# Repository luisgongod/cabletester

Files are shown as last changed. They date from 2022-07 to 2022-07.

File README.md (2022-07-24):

Eurorack Arduino 10/16 pin IDC Power Cable Tester
=================================================

Forked from [holmesrichards](https://github.com/holmesrichards/cabletester) Original idea and testing algorithm goes to [tomarus](https://github.com/tomarus/cabletester ). This version has a new PCB and Some modifications to the FW made into a Platformio project.

* It only tests (max) 8 wires because of how they're wired in eurorack.
* It can detect shorted cables or faulty/unconnected wires.
* Possible to run a _calibration_ sketch for more accurate readings.
* `GND-VCC-SCL-SDA` and `VCC-GND-SCL-SDA` Oled configuration allowed.
* JLCPCB Gerber ready zip

The original documentation and repo information is under _OGs_ folder. Gerbers, schematics and BOM are under _HW_ while the Platformio project is under _FW_.

# Calibration

Default values should work fine:
```
const int expect[] = {746, 544, 395, 286, 204, 130, 80, 35};
```
But is recommended to make a _calibration_ run to change to proper values. To do that:
- Define `DEBUG` mode by uncommenting line 7. 
- Plug a 16 pin Cable that is known to be work fine. 
- Flash the arduino and open Serialmonitor. the `expect` values will be printed, they should not differ too much from default values. 
- Change the `expect` values, comment the `DEBUG` define and re-flash

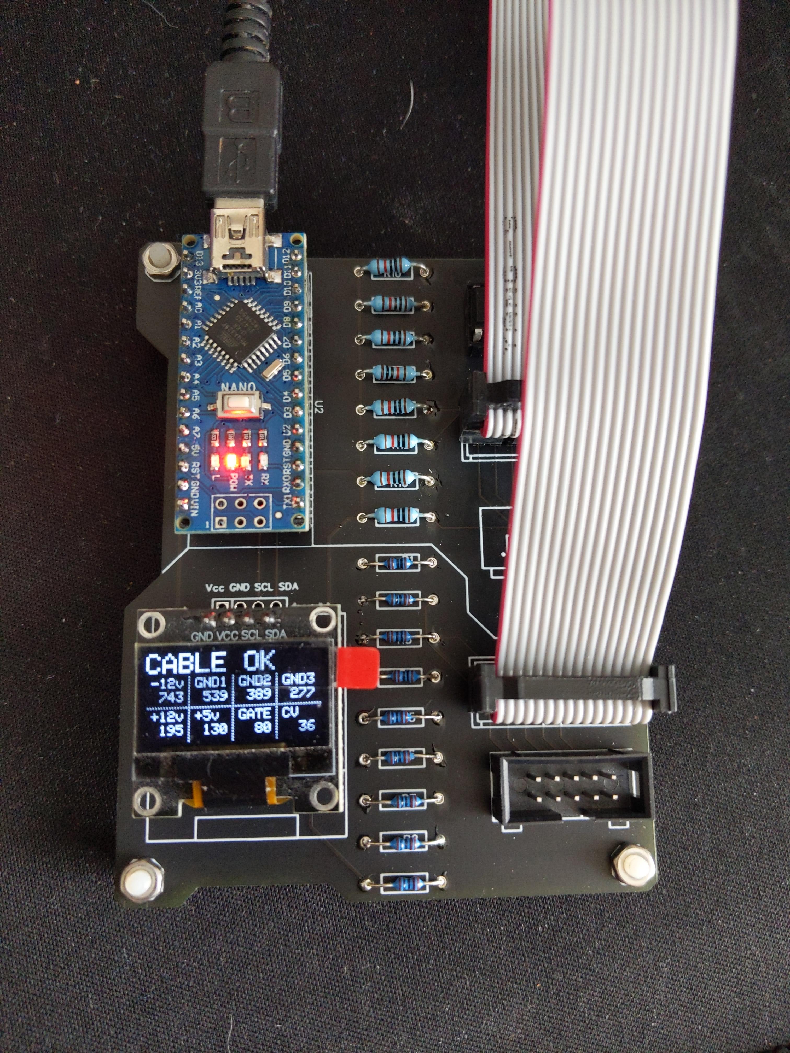
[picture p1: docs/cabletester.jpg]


# Schematics

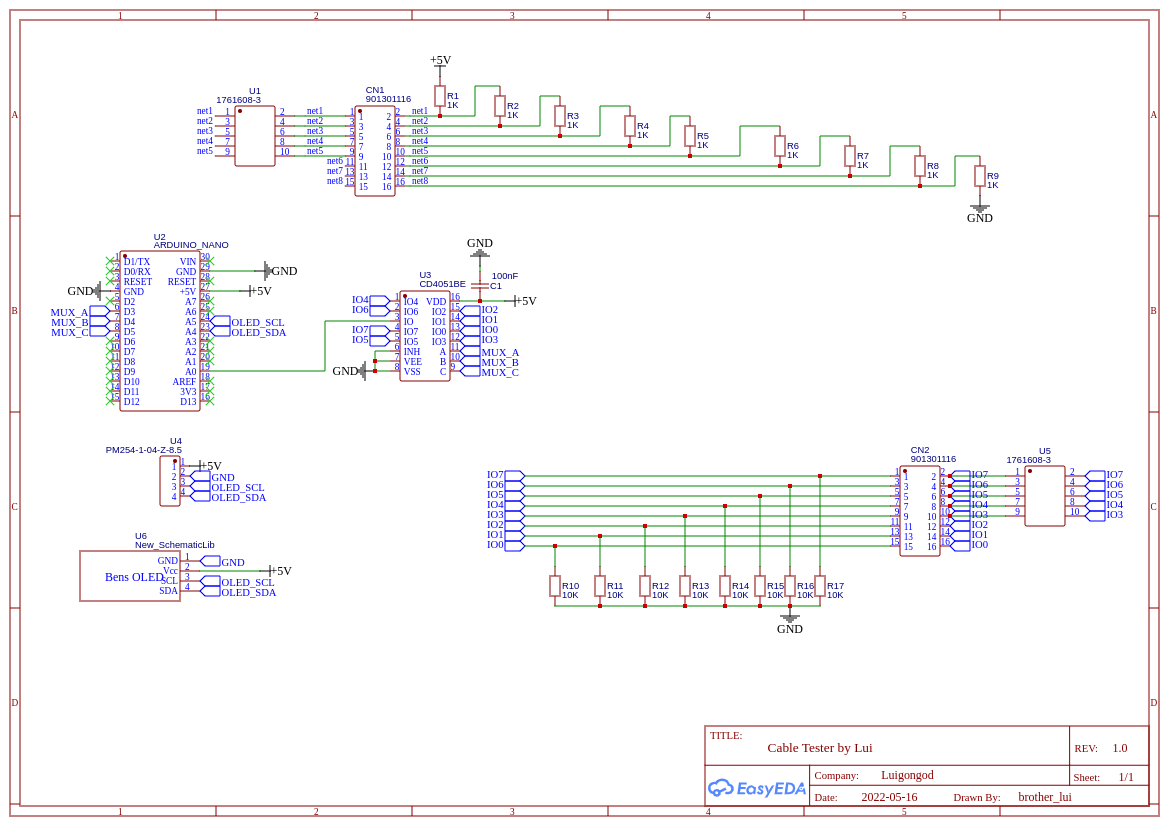
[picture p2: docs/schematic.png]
schematics


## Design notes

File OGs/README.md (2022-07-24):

Arduino 10/16 pin Eurorack IDC Power Cable Tester
=================================================

Forked from [https://github.com/tomarus/cabletester](https://github.com/tomarus/cabletester) with slight modifications to circuit and software (mainly order of connections), and with PCB layout added.

* It only tests (max) 8 wires because of how they're wired in eurorack.
* It can detect shorted cables or faulty/unconnected wires.

This project uses a 128x64 OLED I2C display module with four interface pins: GND, +12V, SCL, and SDA. It is a monochrome display although it is available in a version with a yellow and blue overlay as seen in the photos. Note that the OLED pinout sometimes is GND-VCC-SCL-SDA and sometimes VCC-GND-SCL-SDA. The initial run of boards assumed the latter pinout; the present design has footprints for both.

These modules are available from the "usual suspects" on Amazon, eBay, AliExpress, etc. I have one of [these](https://www.amazon.com/gp/product/B072Q2X2LL) (GND-VCC-SCL-SDA) and one of [these](https://www.amazon.com/gp/product/B07FK8GB8T) (VCC-GND-SCL-SDA). They do *not* seem to be available from any established vendors like Mouser, DigiKey, Tayda, Adafruit, or SparkFun. Please make sure you have a source for the display before proceeding with this project! 

Code uses these libraries:

* https://github.com/adafruit/Adafruit_SSD1306
* https://github.com/adafruit/Adafruit-GFX-Library

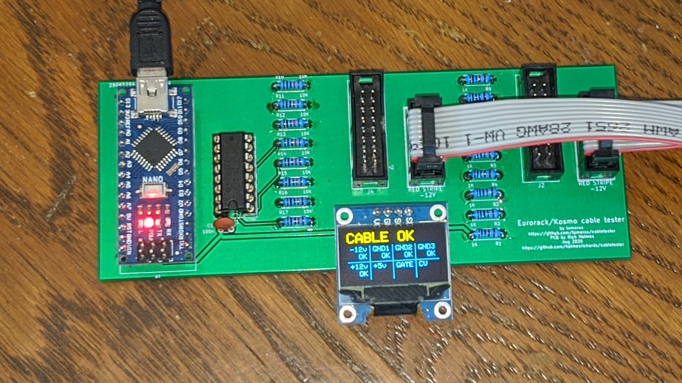
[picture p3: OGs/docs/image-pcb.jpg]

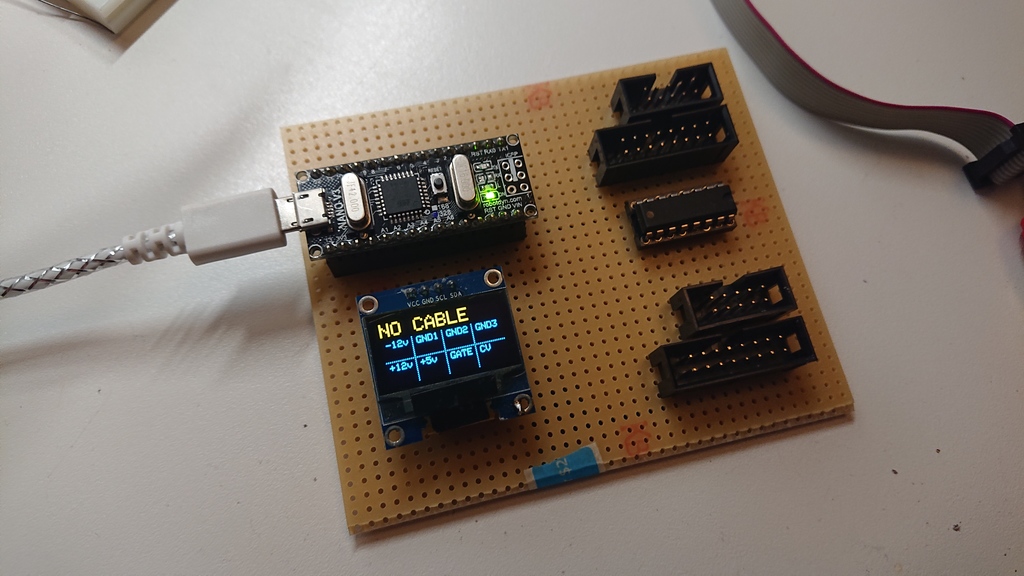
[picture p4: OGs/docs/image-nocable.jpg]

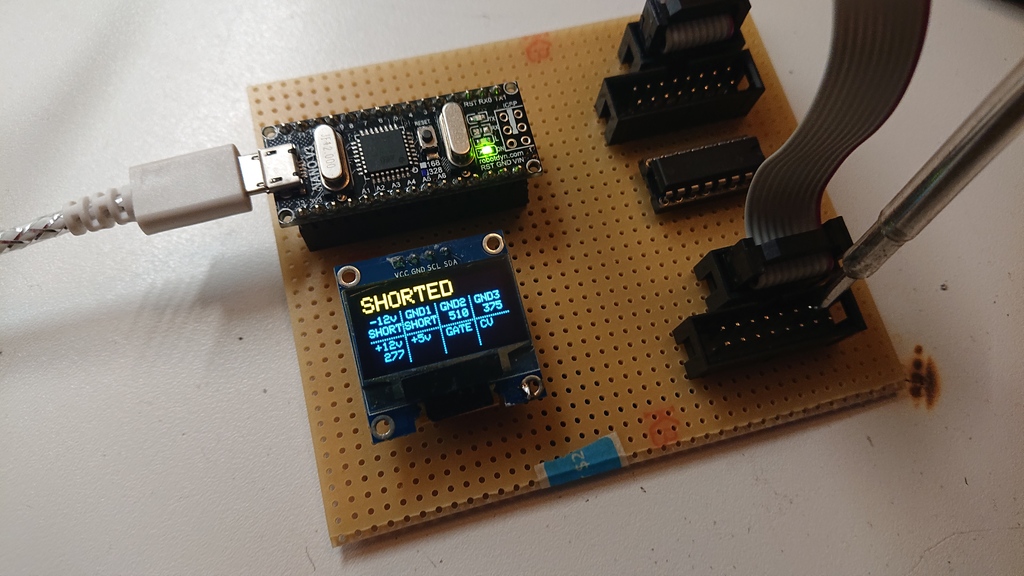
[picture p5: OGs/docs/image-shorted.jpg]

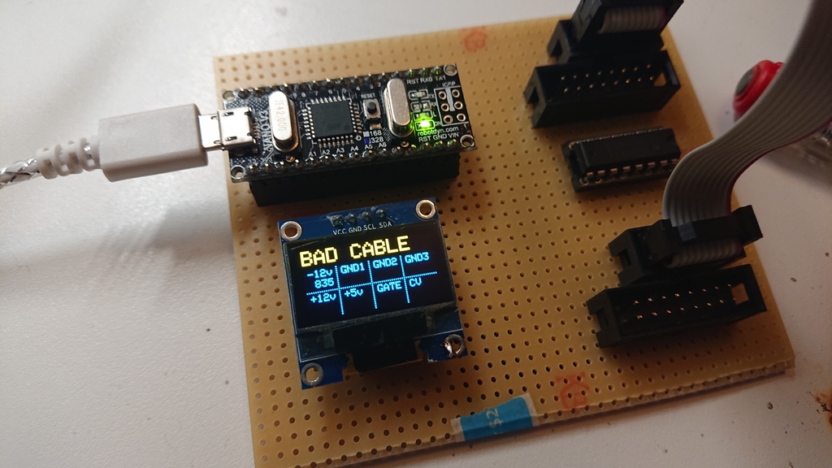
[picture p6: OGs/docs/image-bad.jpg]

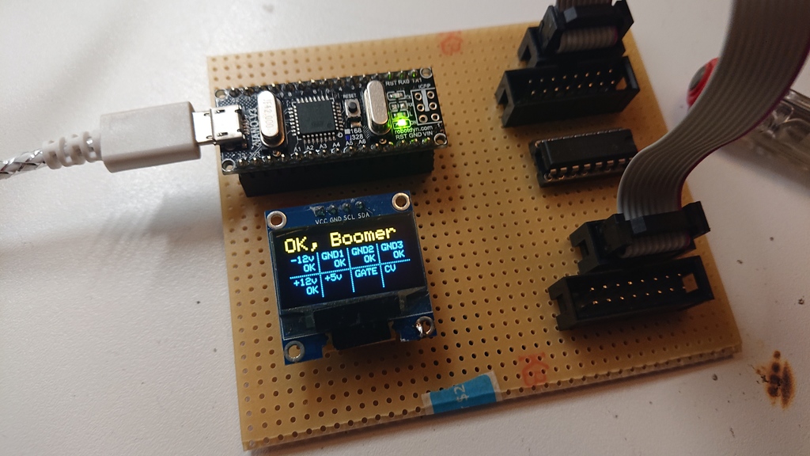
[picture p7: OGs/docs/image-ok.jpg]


# Schematics

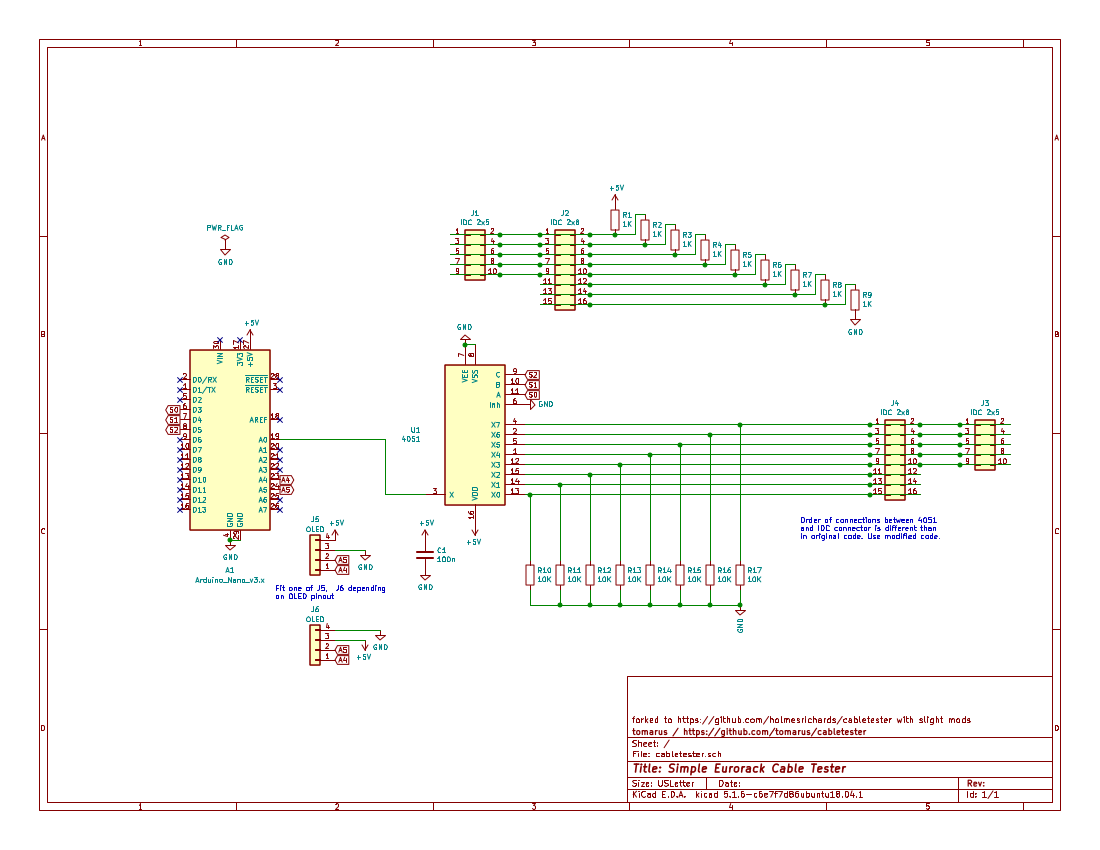
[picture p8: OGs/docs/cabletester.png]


# PCB

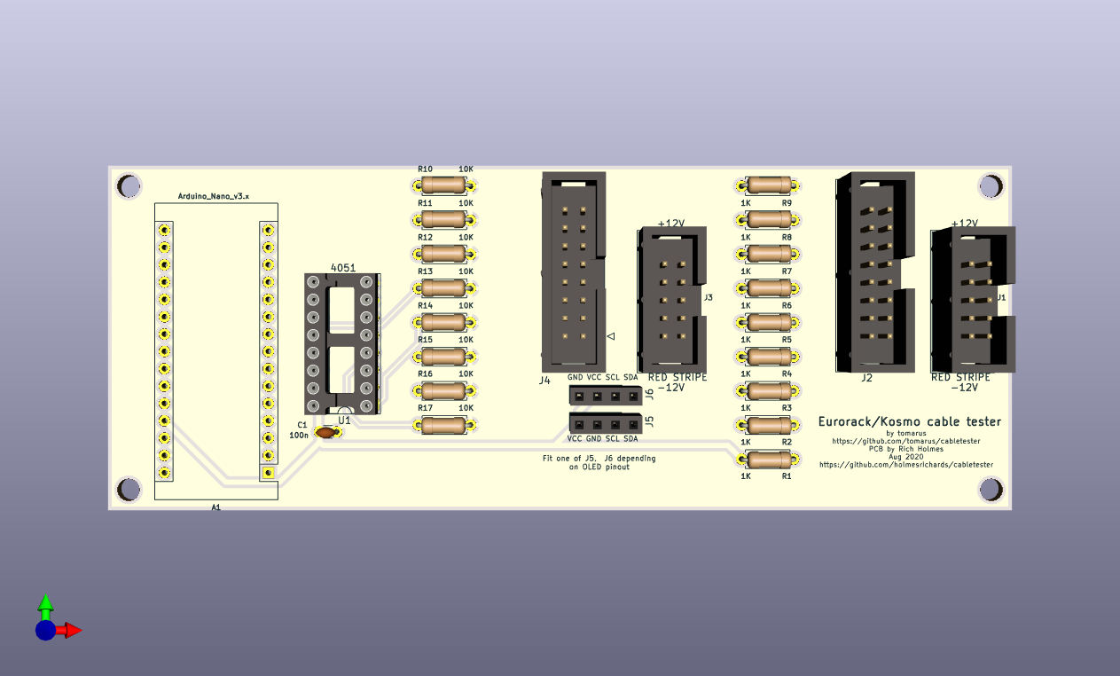
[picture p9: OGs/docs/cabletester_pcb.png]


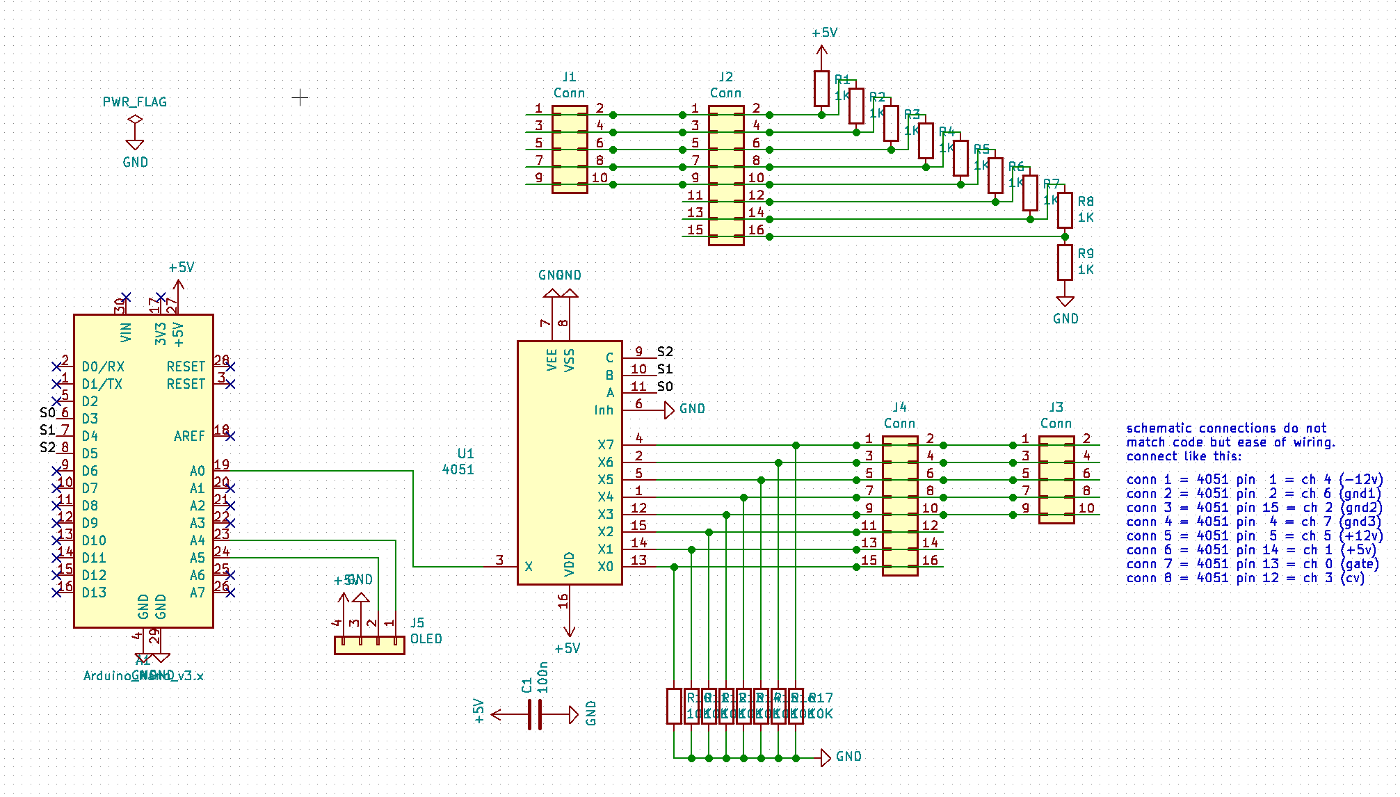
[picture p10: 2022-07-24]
OGs/docs/schematics.png

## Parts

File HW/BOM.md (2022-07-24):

# BOM

**Component Count:** 26

| **ID** | **Tyoe** | **Designator** | **Quantity** | **Value** |
|---|---|---|---|---|
| 1 | Ceramic Cap | C1 | 1 | 100nF |
| 2 | 16 IDC | CN1,CN2 | 2 | |
| 3 | Resistor | R1,R2,R3,R4,R5,R6,R7,R8,R9 | 9 | 1kΩ |
| 4 | Resistor | R10,R11,R12,R13,R14,R15,R16,R17 | 8 | 10kΩ |
| 5 | 10 IDC | U1,U5 | 2 | |
| 6 | Arduino Nano | U2 | 1 | |
| 7 | CD4051BE | U3 | 1 | |
| 8 | Oled Connector | U4 | 1 | 4 pin header |
| 9 | Oled Connector | U6 | 1 | 4 pin header |

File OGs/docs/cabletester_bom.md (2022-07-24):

# cabletester BOM

Tue 11 Aug 2020 08:37:09 AM EDT

Generated from schematic by Eeschema 5.1.6-c6e7f7d~86~ubuntu18.04.1

**Component Count:** 26

| Value | Qty | Part | Description | Vendor |
| ----- | --- | ---- | --- | --- |
| A1 | 1 | Arduino_Nano_v3.x | Arduino Nano v3.x | Tayda A-2864 |
| C1 | 1 | 100 nF | Unpolarized capacitor | Tayda A-564 |
| J1, J3 | 2 | IDC 2x5 | Eurorack style 10 pin power header | Tayda A-2939 |
| J2, J4 | 2 | IDC 2x8 | Eurorack style 16 pin power header | Tayda A-2956 |
| J5, J6 | 1 | 4 pin header | 4 pin female 2.54 mm header (fit in one of two locations) | Tayda A-1303 |
| R1, R2, R3, R4, R5, R6, R7, R8, R9 | 9 | 1K | Resistor | Tayda A-2200 |
| R10, R11, R12, R13, R14, R15, R16, R17 | 8 | 10K | Resistor | Tayda A-2203 |
| U1 | 1 | 4051 | Analog Multiplexer 8 to 1 | Tayda A-026 |
| – | 1 | – | 128x64 monochrome I2C OLED module | eBay, AliExpress... |

See [README](../README.md) for notes on OLED module.

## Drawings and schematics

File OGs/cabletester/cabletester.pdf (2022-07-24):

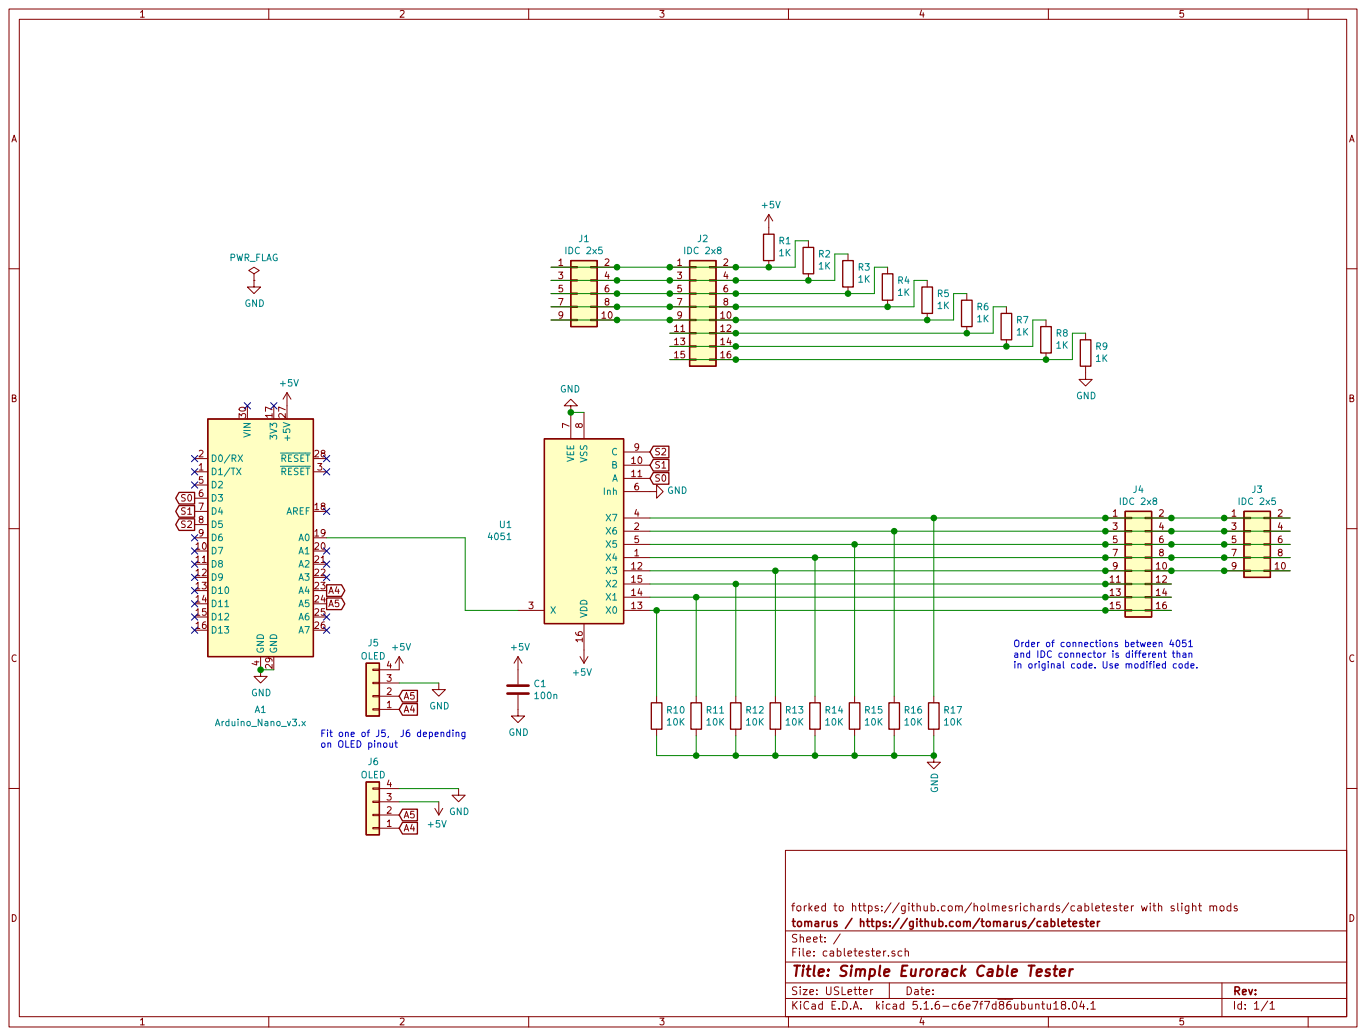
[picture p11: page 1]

and IDC connector is different than
in original code. Use modified code.

Fit one of J5, J6 depending
on OLED pinout

forked to https://github.com/holmesrichards/cabletester with slight mods
Id: 1/1 Title: Simple Eurorack Cable Tester File: cabletester.sch Sheet: / tomarus / https://github.com/tomarus/cabletester

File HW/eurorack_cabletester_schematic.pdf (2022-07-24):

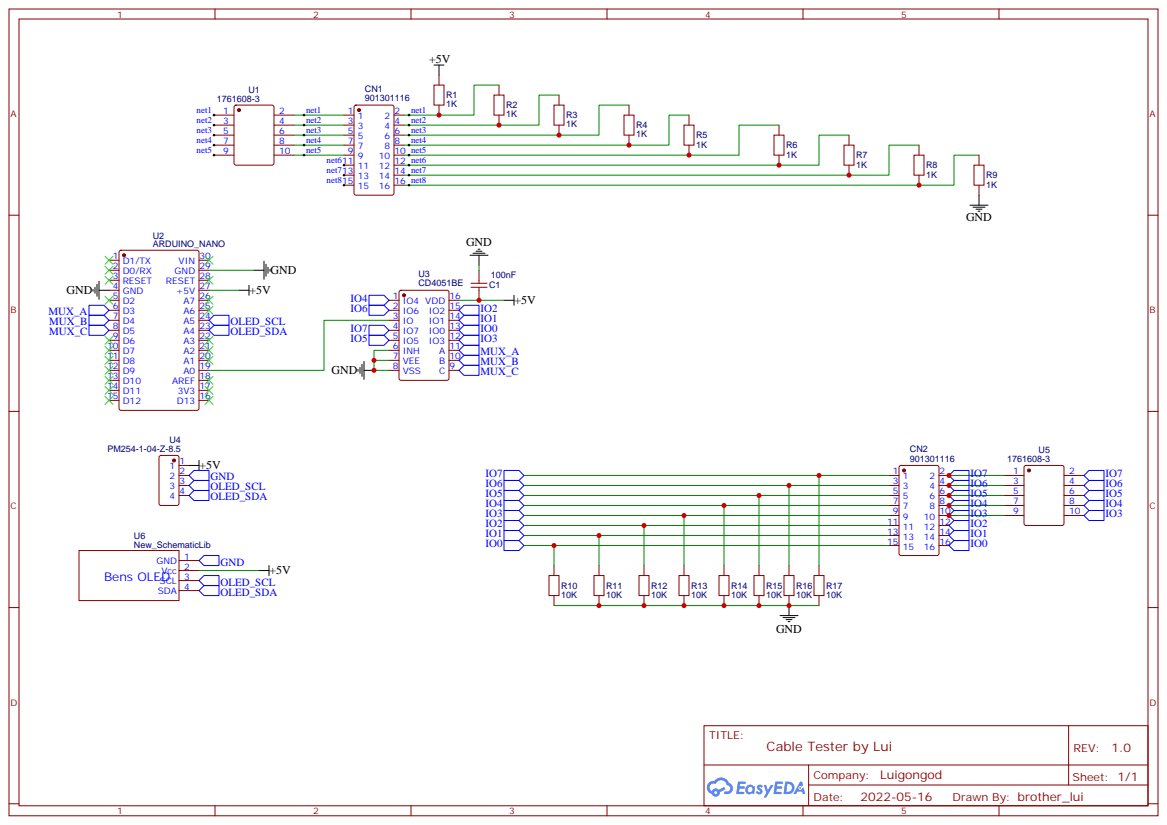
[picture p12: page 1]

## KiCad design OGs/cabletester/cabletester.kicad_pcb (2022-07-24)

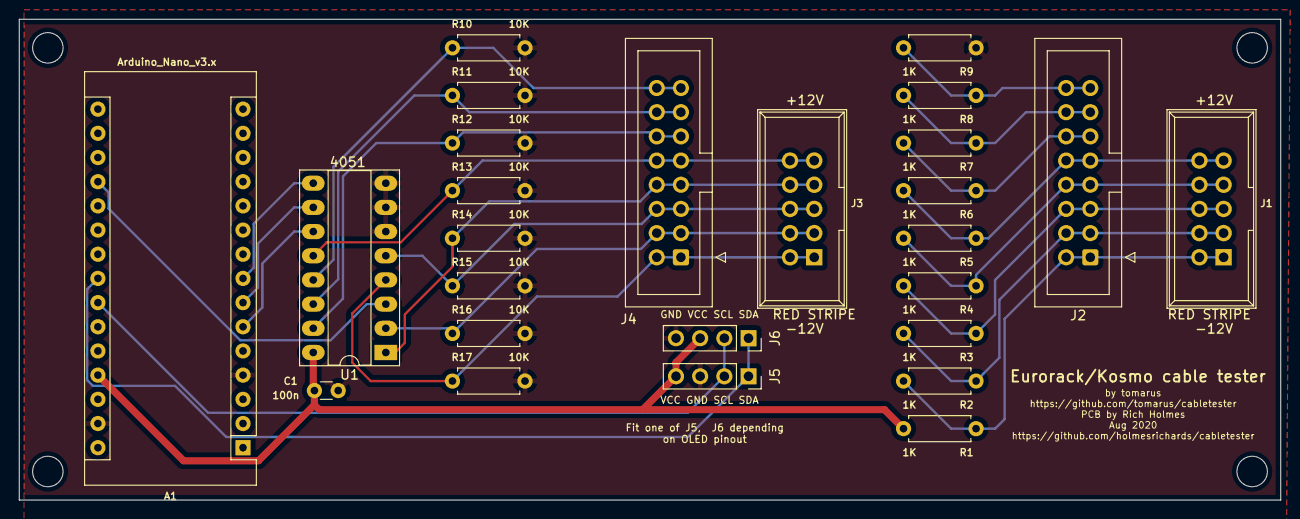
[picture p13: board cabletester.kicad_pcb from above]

Board: 2 copper layers, 132.5 x 50.5 mm, 26 parts (0 on the bottom side), 24 nets.

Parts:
A1: Arduino_Nano_v3.x; Arduino_Nano
C1: 100n; C_Disc_D3.0mm_W1.6mm_P2.50mm
J1, J3: IDC 2x5; Power_Header
J2, J4: IDC 2x8; IDC-Header_2x08_P2.54mm_Vertical
J5, J6: 4 pin header; PinSocket_1x04_P2.54mm_Vertical
R1, R2, R3, R4, R5, R6, R7, R8, R9: 1K; R_Axial_DIN0207_L6.3mm_D2.5mm_P7.62mm_Horizontal
R10, R11, R12, R13, R14, R15, R16, R17: 10K; R_Axial_DIN0207_L6.3mm_D2.5mm_P7.62mm_Horizontal
U1: 4051; DIP-16_W7.62mm_Socket_LongPads

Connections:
+5V: A1.27, C1.1, J5.4, J6.3, R1.2, U1.16
A4: A1.23, J5.1, J6.1
A5: A1.24, J5.2, J6.2
GND: A1.4, A1.29, C1.2, J5.3, J6.4, R9.1, R10.2, R11.2, R12.2, R13.2, R14.2, R15.2, R16.2, R17.2, U1.6, U1.7, U1.8
unnamed: A1.19, U1.3
unnamed: J1.1, J1.2, J2.1, J2.2, R1.1, R2.2
unnamed: J1.3, J1.4, J2.3, J2.4, R2.1, R3.2
unnamed: J1.5, J1.6, J2.5, J2.6, R3.1, R4.2
unnamed: J1.7, J1.8, J2.7, J2.8, R4.1, R5.2
unnamed: J1.9, J1.10, J2.9, J2.10, R5.1, R6.2
unnamed: J2.11, J2.12, R6.1, R7.2
unnamed: J2.13, J2.14, R7.1, R8.2
unnamed: J2.15, J2.16, R8.1, R9.2
unnamed: J3.1, J3.2, J4.1, J4.2, R17.1, U1.4
unnamed: J3.3, J3.4, J4.3, J4.4, R16.1, U1.2
unnamed: J3.5, J3.6, J4.5, J4.6, R15.1, U1.5
unnamed: J3.7, J3.8, J4.7, J4.8, R14.1, U1.1
unnamed: J3.9, J3.10, J4.9, J4.10, R13.1, U1.12
unnamed: J4.11, J4.12, R12.1, U1.15
unnamed: J4.13, J4.14, R11.1, U1.14
unnamed: J4.15, J4.16, R10.1, U1.13
S0: A1.6, U1.11
S1: A1.7, U1.10
S2: A1.8, U1.9

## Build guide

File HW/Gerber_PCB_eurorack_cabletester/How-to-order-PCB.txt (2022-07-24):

How to Order PCB

Please refer to:
https://docs.easyeda.com/en/PCB/Order-PCB

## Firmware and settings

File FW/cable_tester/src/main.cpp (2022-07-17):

#include <Adafruit_SSD1306.h>
#include <Arduino.h>

#define OLED_ADDR 0x3C
Adafruit_SSD1306 display(128, 64);

// #define DEBUG //Use for calibration too

#define PIN_4051_S0 3
#define PIN_4051_S1 4
#define PIN_4051_S2 5
#define PIN_4051_A A0
#define NSAMPLES 20  // number of samples to take for each measurement

const char *labels[] = {"-12v", "GND1", "GND2", "GND3",
                        "+12v", "+5v",  "GATE", "CV"};

const int order[] = {
    7,  // cv
    6,  // gate
    5,  // +5v
    4,  // +12v
    3,  // gnd3
    2,  // gnd2
    1,  // gnd1
    0   // -12v
};

// allow some fluctuation on our ADC
const int margin = 20;

// expected values (+/- margin)
// Use Define DEBUG and serialmonitor to see the values to be used:
const int expect[] = {746, 544, 395, 286, 204, 130, 80, 35};
						

const int open_threshold = 15;

int cable_status = 0;
int prev_status = -1;
const char *statuses[] = {"CABLE OK", "NO CABLE", "SHORTED", "BAD CABLE"};

int values[] = {1, 1, 1, 1, 1, 1, 1, 1};
int newvalues[] = {0, 0, 0, 0, 0, 0, 0, 0};

void hdotline(int y) {
  for (int i = 1; i < display.width(); i += 2) {
    display.drawPixel(i, y, SSD1306_WHITE);
  }
}

void vdotline(int x) {
  for (int i = 17; i < display.height(); i += 2) {
    display.drawPixel(x, i, SSD1306_WHITE);
  }
}

// inmargin checks if value is within the expected range
bool inmargin(const int value, const int expect) {
  return value > expect - margin && value < expect + margin;
}

// check_status checks for shorts, nr of unconnected wires, etc
void check_status() {
  int allok = 0;
  int nc = 0;
  int shrt = 0;

  for (int i = 0; i < 8; i++) {
    int prev = i == 0 ? 7 : i - 1;
    int next = i == 7 ? 0 : i + 1;

    if (values[i] < open_threshold) {
      nc++;
    } else if (inmargin(values[i], values[prev]) ||
               inmargin(values[i], values[next])) {
      shrt++;
    } else if (inmargin(values[i], expect[i])) {
      allok++;
    }
  }

  // advanced algorithm to decide on the cable status
  if (allok == 8 || (allok == 5 && nc == 3)) {
    // everything should be ok
    cable_status = 0;
  } else if (nc == 8) {
    // no cable
    cable_status = 1;
  } else if (shrt > 0) {
    // shorted somewhere
    cable_status = 2;
  } else {
    // otherwise a bad cable
    cable_status = 3;
  }
}

// draw_status renders the global status on top of the screen
void draw_status() {
  if (cable_status != prev_status) {
    prev_status = cable_status;
    display.setTextSize(2);
    display.setCursor(0, 0);
    display.print("          ");
    display.setCursor(0, 0);
    display.print(statuses[cable_status]);
  }
}

// align_value right aligns a 4-digit number for a 6px font width.
void align_value(int x, int y, int v) {
  int off = v < 10 ? 18 : v < 100 ? 12 : v < 1000 ? 6 : 0;
  display.setCursor(x + off, y);
  display.print(v);
}

// draw_value renders one of the eight display boxes.
void draw_value(const int n) {
  if (newvalues[n] == values[n])
    // return early, do nothing if the value isn't changed
    return;

  values[n] = newvalues[n];
  int v = values[n];

  int x = (n & 3) * 32;
  int y = n < 4 ? 28 : 52;
  display.setCursor(x, y);
  display.print("     ");

  if (v < 5) {
    // return early, 0 volt, unconnected wire,
    // display nothing for unconnected wires
    return;
  }

  int prev = n == 0 ? 7 : n - 1;
  int next = n == 7 ? 0 : n + 1;
  if (values[n] >= open_threshold && (inmargin(values[n], values[prev]) ||
                                      inmargin(values[n], values[next]))) {
    // If our next or previous value is the same (+/- margin)
    // there is probably a short circuit.
    display.setCursor(x + 1, y);
    display.print("SHORT");
  } else if (inmargin(values[n], expect[n])) {
#ifdef DEBUG
    align_value(x + 4, y, v);
#else
    {
      display.setCursor(x + 16, y);
      display.print("OK");
    }
#endif
  } else if (values[n] >= open_threshold) {
    // Display raw ADC value if out of limits.
    align_value(x + 4, y, v);
  }
}

// reads ADC and returns average of number of nsamples
int sampleADC(int nsamples) {
  int v = 0;
  for (int i = 0; i < nsamples; i++) {
    v += analogRead(PIN_4051_A);
  }
  return v / nsamples;
}

// read_values updates all values from the 4051 mux.
void read_values() {
  for (int i = 0; i < 8; i++) {
    digitalWrite(PIN_4051_S0, i & 0b001);
    digitalWrite(PIN_4051_S1, i & 0b010);
    digitalWrite(PIN_4051_S2, i & 0b100);
    delay(100);
    newvalues[order[i]] = sampleADC(NSAMPLES);
  }
}

#ifdef DEBUG
void db_print_values() {
  for (int i = 0; i < 8; i++) {
    Serial.print(newvalues[i]);
    Serial.print(" ");
  }
  Serial.println();
}
#endif

void setup() {
#ifdef DEBUG
  Serial.begin(9600);
#endif

  display.begin(SSD1306_SWITCHCAPVCC, OLED_ADDR);
  display.clearDisplay();
  display.display();

  pinMode(PIN_4051_S0, OUTPUT);
  pinMode(PIN_4051_S1, OUTPUT);
  pinMode(PIN_4051_S2, OUTPUT);

  display.setTextColor(WHITE, BLACK);
  display.setTextSize(1);
  for (int i = 0; i < 8; i++) {
    int x = (i & 3) * 32;
    int y = i < 4 ? 18 : 42;
    display.setCursor(x + 4, y);
    display.print(labels[i]);
  }

  hdotline(39);
  vdotline(31);
  vdotline(63);
  vdotline(95);
  display.display();
}

void loop() {
  read_values();
  check_status();
  display.setTextSize(1);
  for (int i = 0; i < 8; i++) {
    draw_value(i);
    display.display();
  }
  draw_status();
  display.display();

#ifdef DEBUG
  db_print_values();
  delay(500);
#endif

  delay(500);
}

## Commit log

2022-07-17 ✨ working pcb
2022-07-24 🔖 Release
    [Eurorack_cabletester.schdoc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]
2022-07-24 📝 zip reference
